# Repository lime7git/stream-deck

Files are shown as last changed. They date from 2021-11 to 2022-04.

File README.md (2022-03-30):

# stream-deck
 
TO DO:

- ADD RESET BUTTON                                     #CHECK
- CHANGE SWD TO GOLDPINS                               #CHECK
- ADD TWO STATUS LED DIODES                            #CHECK
- ADD FOOTPRINTS FOR MX CHERRY REPLACEMENT SWITCHES    #CHECK
- ADD TEST POINTS                                      #CHECK

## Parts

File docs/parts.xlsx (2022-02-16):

Name | Description | Qty | Price | Link
STMicroelectronics STM32F401RCT6 | Microcontroller | 1.0 | 6.723 USD | STM32F401RCT - lcsc.com (https://lcsc.com/product-detail/ST-Microelectronics_STMicroelectronics-STM32F401RCT6_C74524.html)
CHERRY MX 540-MX1A-E1NW | Mechanical pushbutton switch | 9.0 | 0.958 USD | cherry mx - mouser.com (https://pl.mouser.com/ProductDetail/CHERRY/MX1A-E1NW?qs=Z7NFYKyvgJd45Wm4xzFv7w%3D%3D)
ENKODER | Mechanical incremental encoder with switch EC11 | 3.0 | 4.360 USD | enkoder botland (https://botland.com.pl/enkodery/6903-enkoder-z-przyciskiem-20-impulsow-12mm-ec11-pionowy-5szt.html)
LED RGB WS2812B RING | Ring of 8 RGB LED diodes | 1.0 | 2.500 USD | ws2812 RGB LED - botland.pl (https://botland.com.pl/lancuchy-i-matryce-led/6248-pierscien-led-rgb-ws2812b-5050-x-8-diod-30mm.html)
OR Gate | 3 input OR gate for microcontroller reset procedure | 1.0 | 0.126 USD | OR gate - lcsc.com (https://www.lcsc.com/product-detail/Gates_onsemi-NC7SZ332P6X_C185032.html)
WS2812B | Adressable RGB LED diode | 6.0 | 0.058 USD | WS2812B - lcsc.com (https://lcsc.com/product-detail/Light-Emitting-Diodes-LED_XINGLIGHT-XL-5050RGBC-WS2812B_C2843785.html)
 |  |  | SUM
 |  |  | 31.40 USD

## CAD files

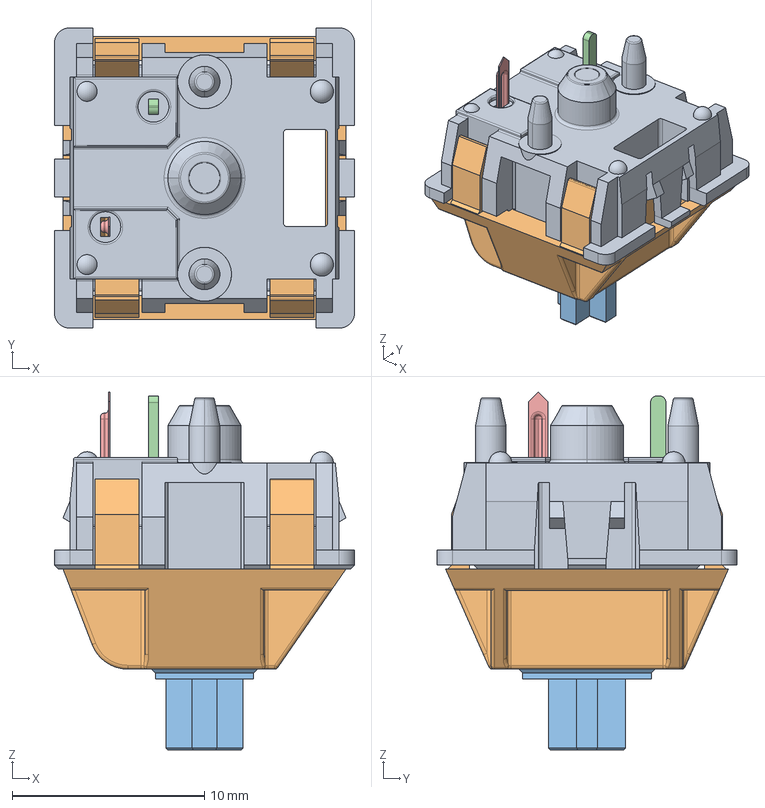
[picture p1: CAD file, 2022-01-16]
pcb/cherry-mx-3d-model/asm_mx_asm_PCB.stp
15.6 x 15.6 x 18.6 mm
MX_DOWN
MX_UP
UP_MX
MX_PIN
MX_SPRING
MX_CLICK

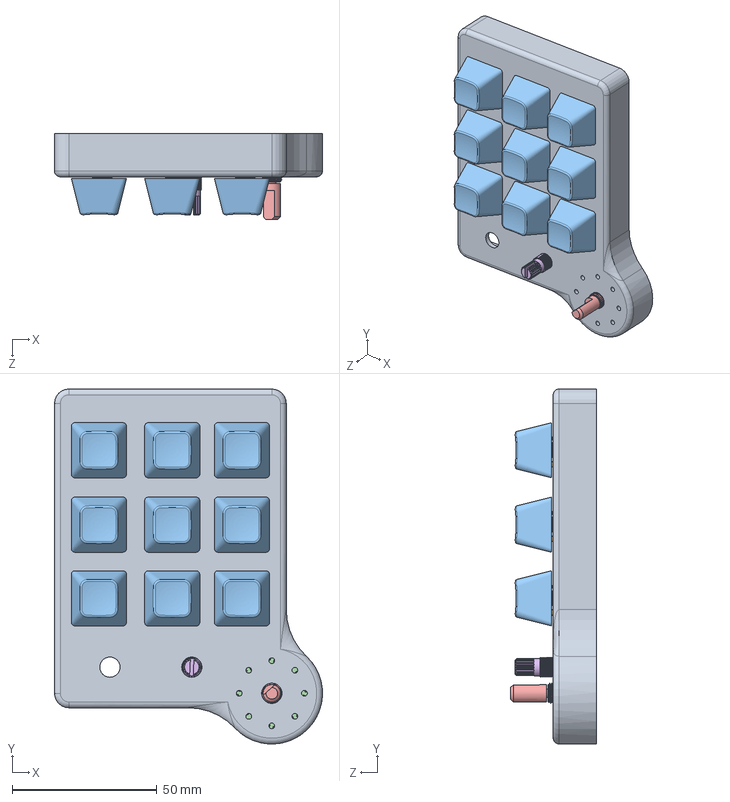
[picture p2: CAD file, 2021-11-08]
3d-model/Złożenie1.SLDASM
92.5 x 122.5 x 29.8 mm
case
cherry_mx x 9
keycap_dsa_signatureplastics_r3 x 9
WS2812_RING_8X
mechanical-encoder
Standard Potentiometer - Horizontal

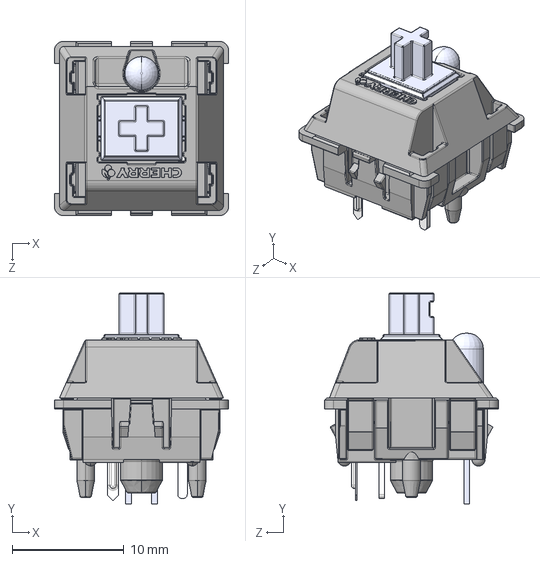
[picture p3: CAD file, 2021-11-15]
3d-model/cherry_mx.STEP
15.6 x 18.9 x 15.6 mm

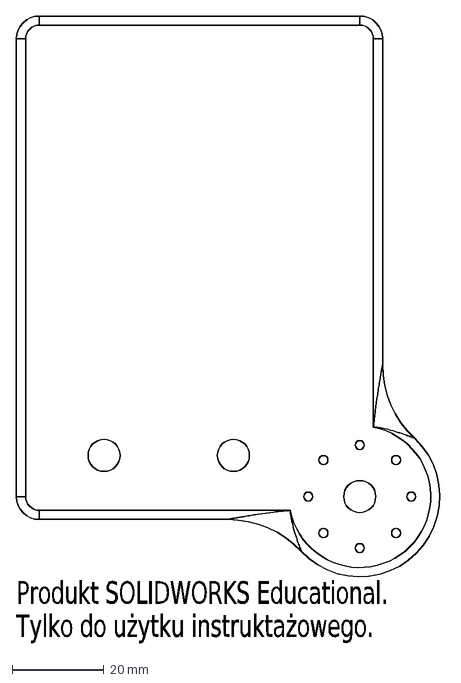
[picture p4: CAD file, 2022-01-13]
pcb/board-edges.DXF
Produkt SOLIDWORKS Educational.
Tylko do użytku instruktażowego.

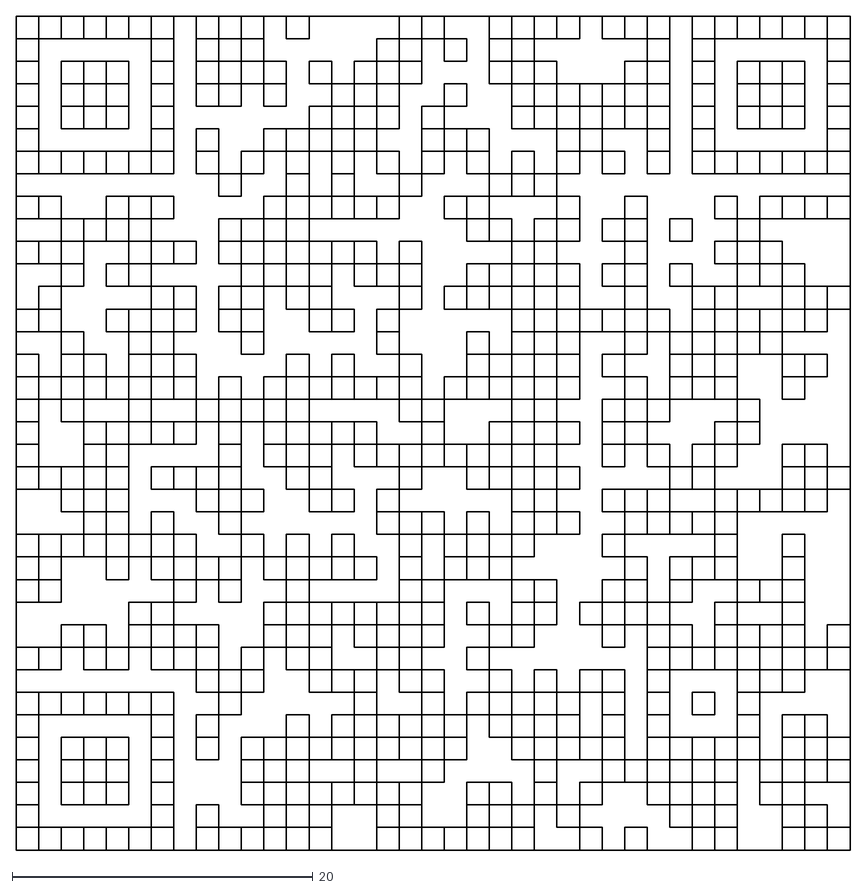
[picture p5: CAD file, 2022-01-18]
pcb/qr-code/qr-code.dxf
55.5 x 55.5

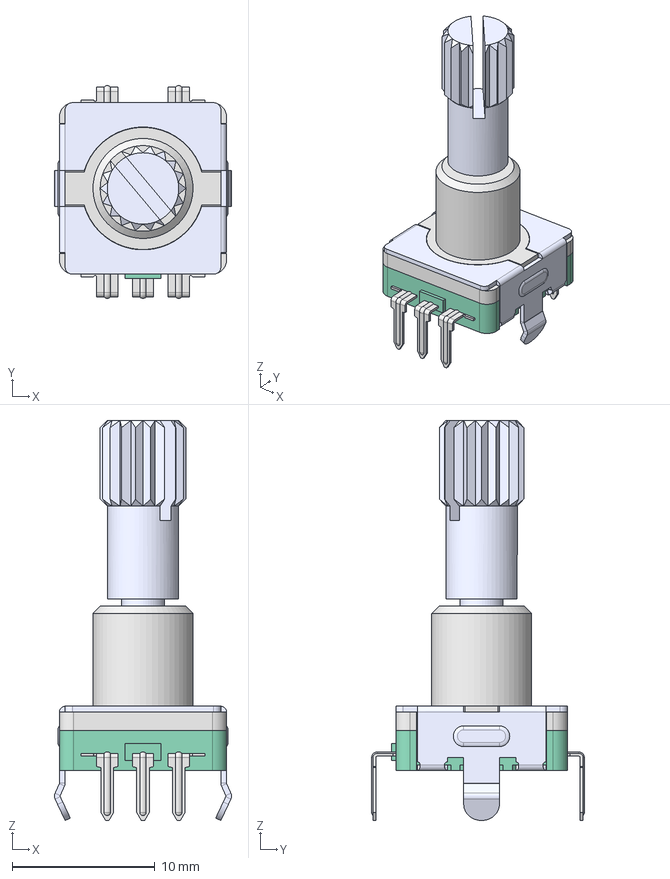
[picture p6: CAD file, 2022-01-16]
pcb/rotary-encoder-3d-model/EC11-THT-20K-green.step
12.4 x 14.9 x 28.0 mm
Lb7
20K
EC11-Housing-THT

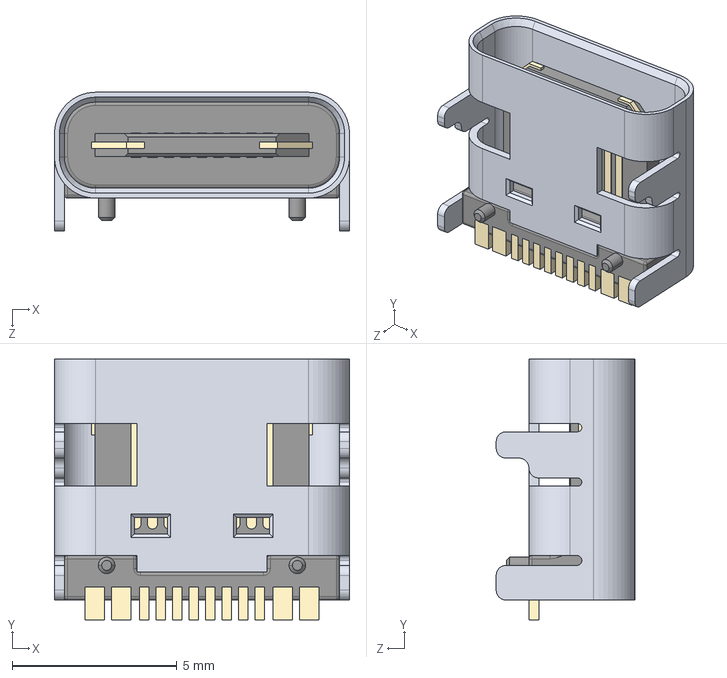
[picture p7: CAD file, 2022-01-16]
pcb/usb-c-smd-3d-model/USB Type C Port (SMD Type).STEP
8.94 x 7.90 x 4.20 mm

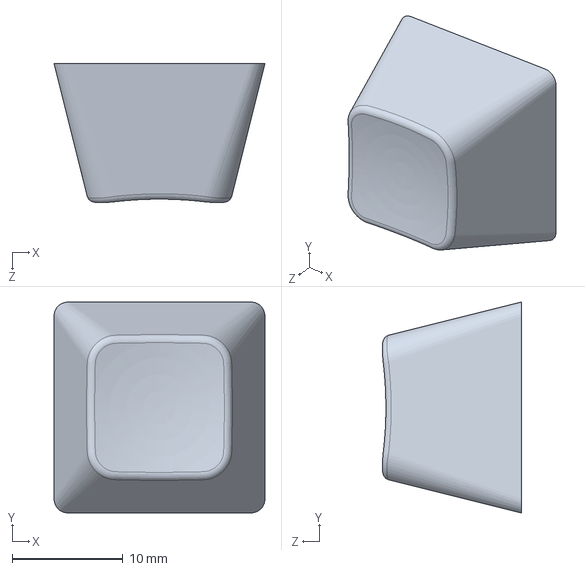
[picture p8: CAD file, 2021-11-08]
3d-model/keycap_dsa_signatureplastics_r3.SLDPRT
19.1 x 19.1 x 12.6 mm

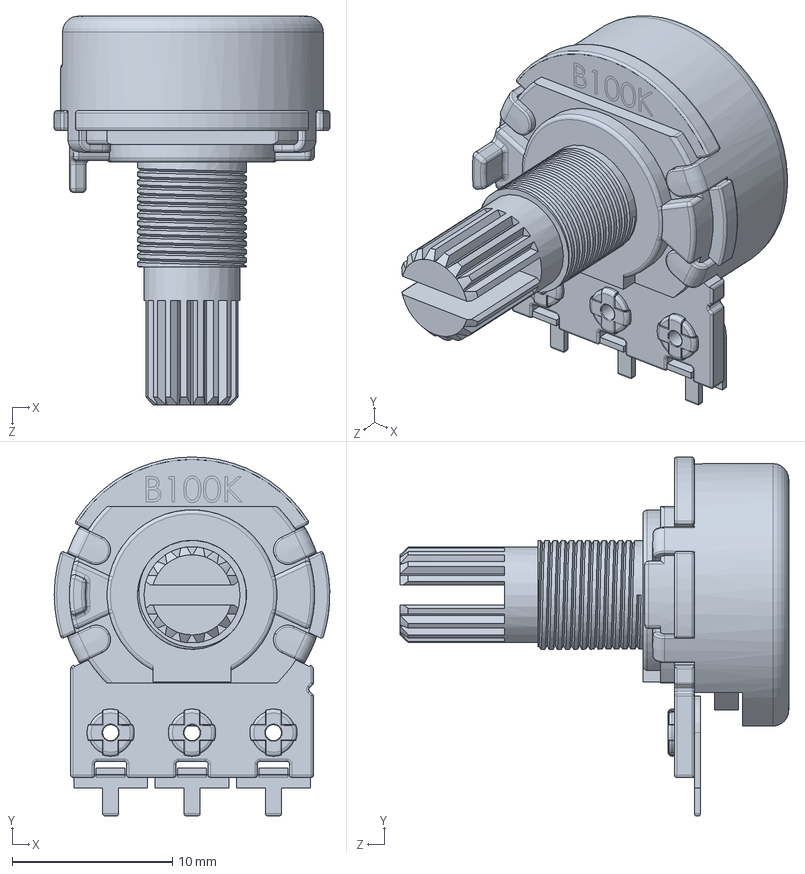
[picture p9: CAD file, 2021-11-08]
3d-model/Standard Potentiometer - Horizontal.SLDPRT
17.2 x 22.4 x 24.2 mm

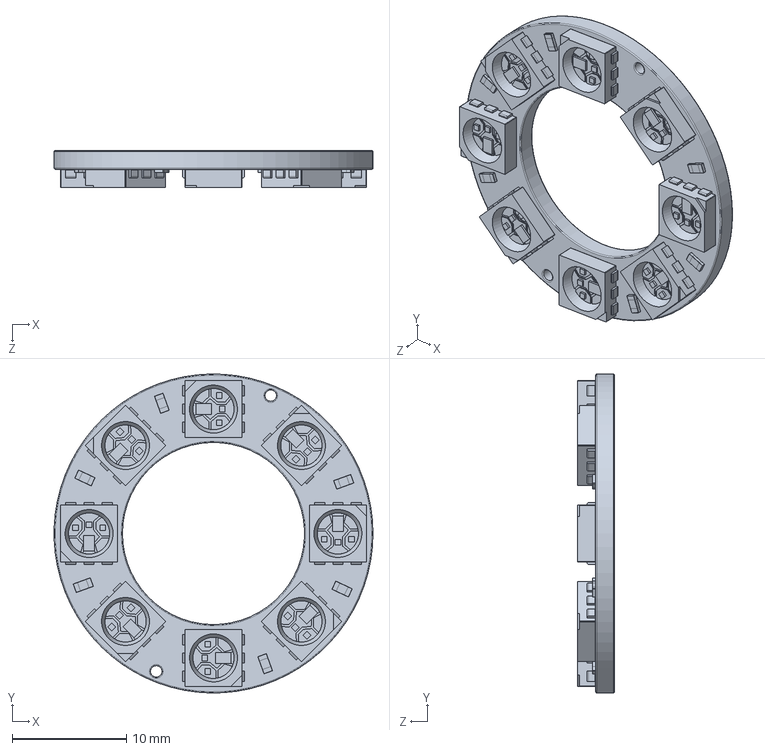
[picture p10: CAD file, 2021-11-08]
3d-model/WS2812_RING_8X.SLDPRT
28.0 x 27.9 x 3.25 mm

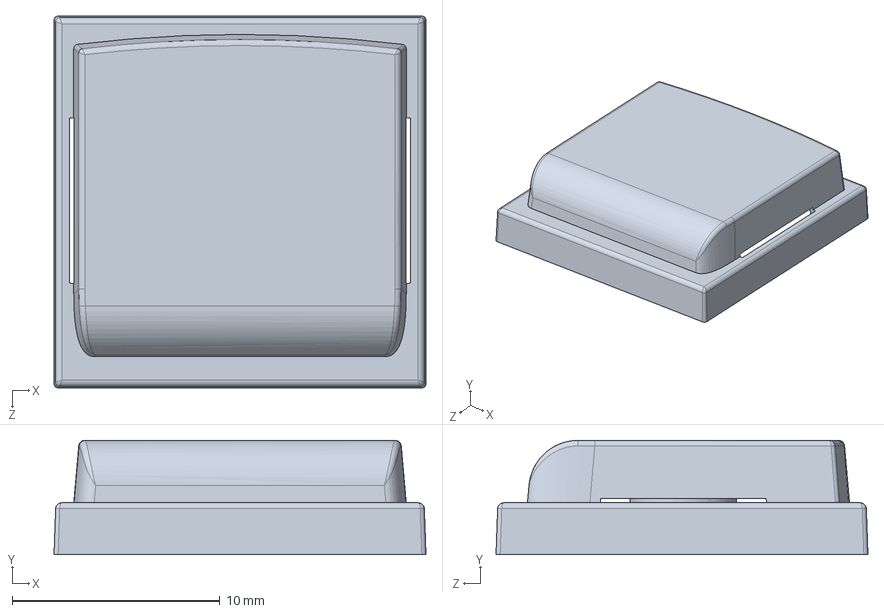
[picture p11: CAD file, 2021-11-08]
3d-model/KEY CAP-CHERRY-MX.SLDPRT
17.9 x 5.50 x 17.9 mm

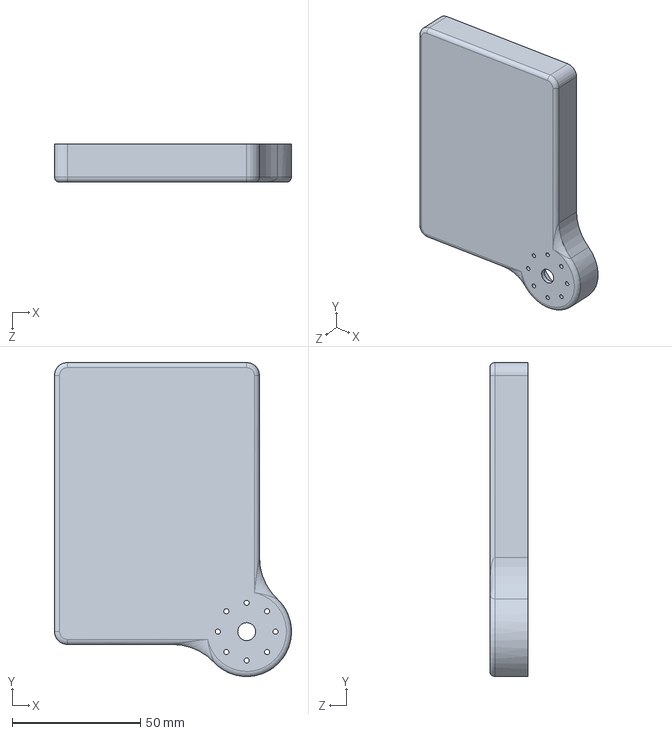
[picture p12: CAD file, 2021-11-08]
3d-model/case.SLDPRT
92.5 x 122.5 x 15.0 mm

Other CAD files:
3d-model/mechanical-encoder.SLDPRT
3d-model/cherry_mx.SLDPRT

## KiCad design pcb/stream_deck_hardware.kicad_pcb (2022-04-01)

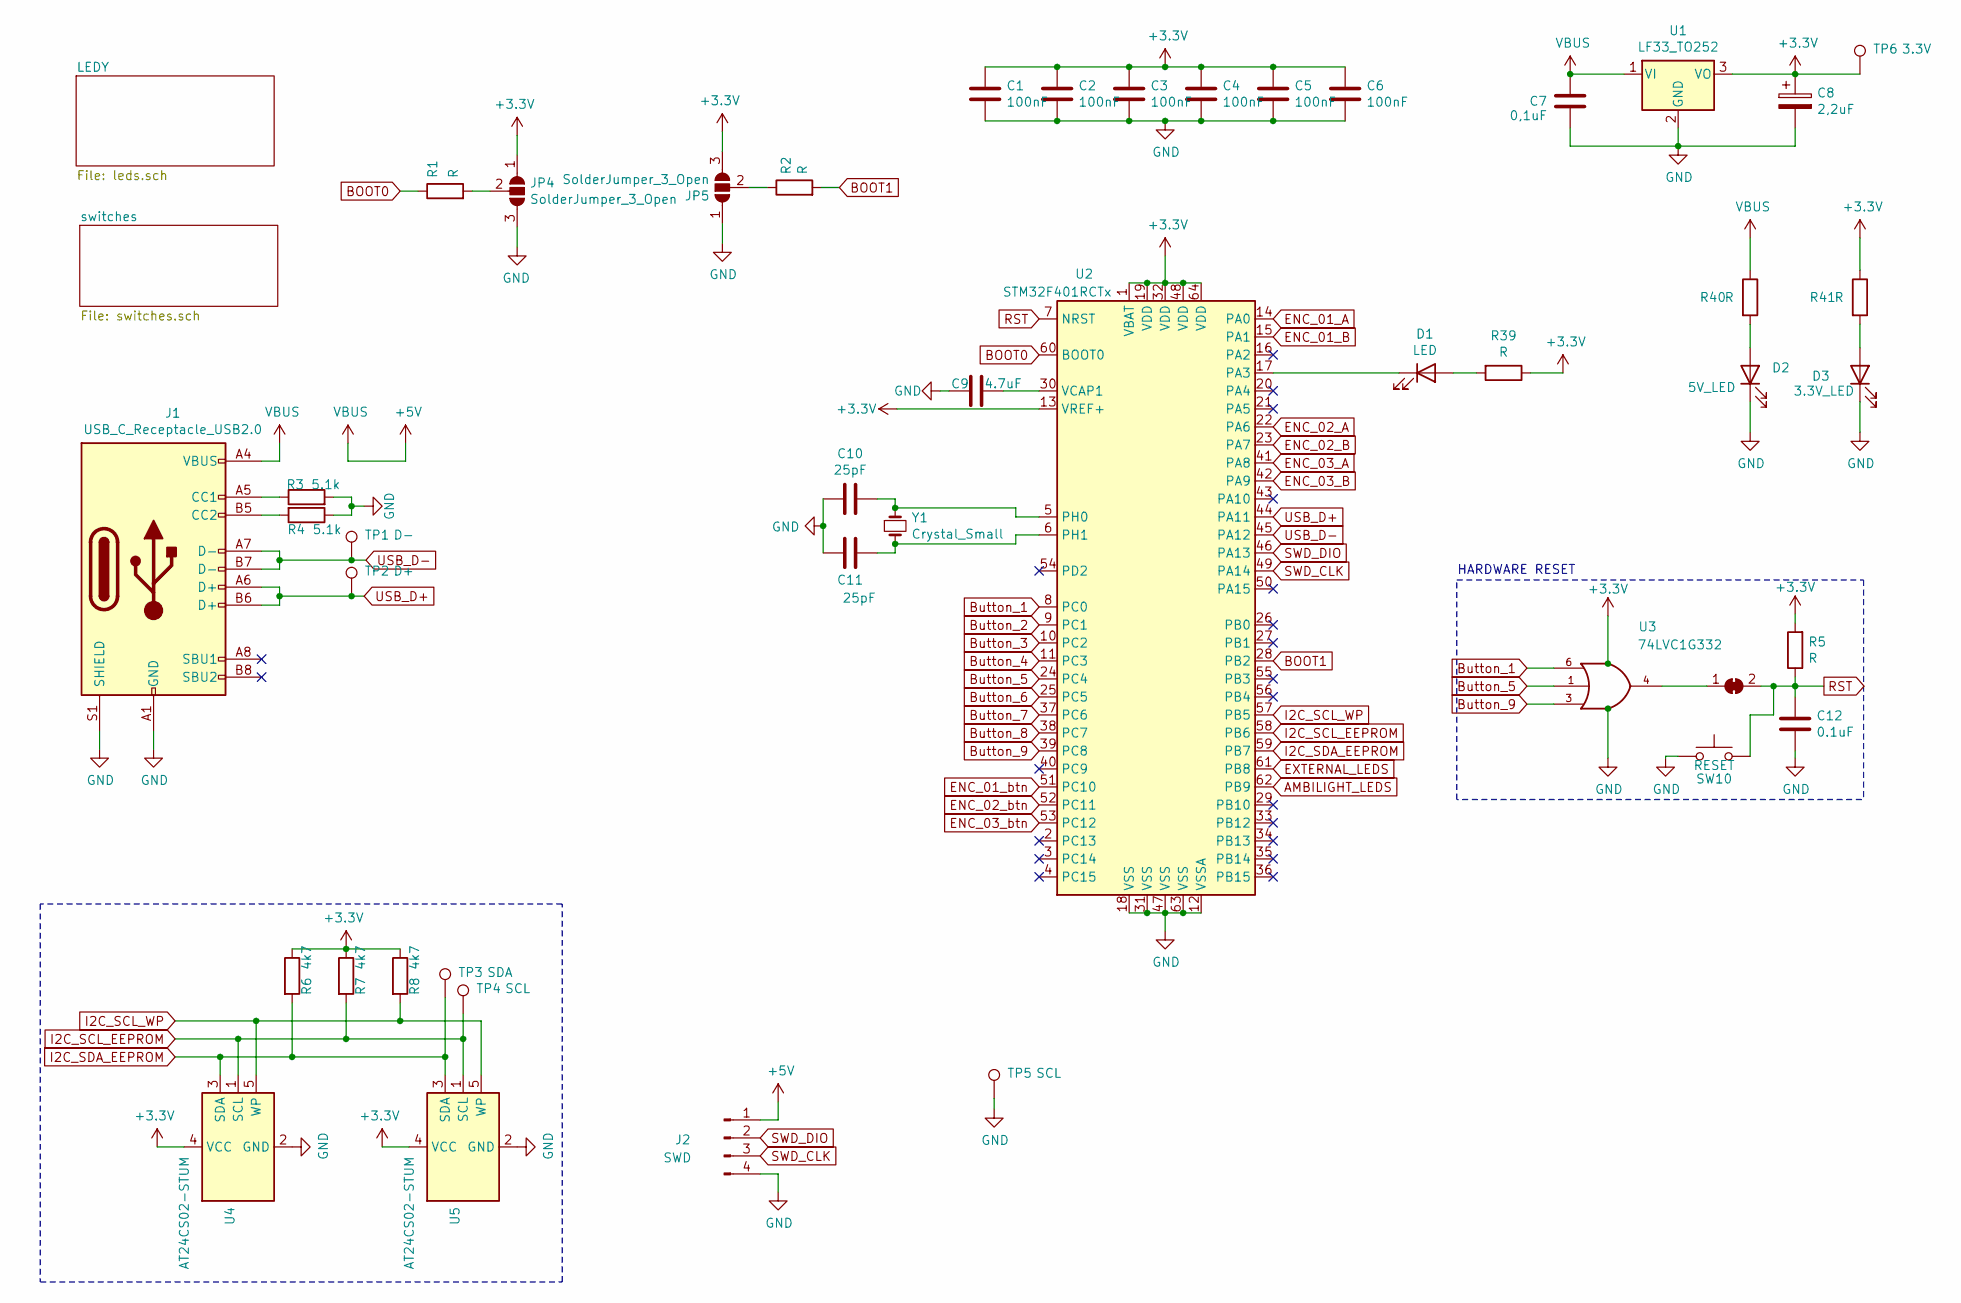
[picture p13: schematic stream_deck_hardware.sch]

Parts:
C1, C2, C3, C4, C5, C6: 100nF; C_0603_1608Metric
C7: 0,1uF; C_0603_1608Metric
C8: 2,2uF; C_0603_1608Metric
C9: 4.7uF; C_0603_1608Metric
C10, C11: 25pF; C_0603_1608Metric
C12: 0.1uF; C_0603_1608Metric
D1: LED; LED_0805_2012Metric
D2: 5V_LED; LED_0805_2012Metric
D3: 3.3V_LED; LED_0805_2012Metric
J1: USB_C_Receptacle_USB2.0; USB_C_Receptacle_Palconn_UTC16-G
J2: SWD; PinHeader_1x04_P2.54mm_Vertical
JP3: SolderJumper_2_Bridged; SolderJumper-2_P1.3mm_Bridged2Bar_RoundedPad1.0x1.5mm
JP4, JP5: SolderJumper_3_Open; SolderJumper-3_P1.3mm_Open_RoundedPad1.0x1.5mm
R1, R2, R5, R39, R40, R41: R; R_0603_1608Metric
R3, R4: 5.1k; R_0603_1608Metric
R6, R7, R8: 4k7; R_0603_1608Metric
SW10: RESET; SW_PUSH_6mm
TP1: D-; TestPoint_Pad_D2.0mm
TP2: D+; TestPoint_Pad_D2.0mm
TP3: SDA; TestPoint_Pad_D2.0mm
TP4, TP5: SCL; TestPoint_Pad_D2.0mm
TP6: 3.3V; TestPoint_Pad_D2.0mm
U1: LF33_TO252; TO-252-2
U2: STM32F401RCTx; LQFP-64_10x10mm_P0.5mm
U3: 74LVC1G332; SOT-23-6
U4, U5: AT24CS02-STUM; SOT-23-5
Y1: Crystal_Small; Crystal_HC49-U_Vertical

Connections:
+3V3: C1.1, C2.1, C3.1, C4.1, C5.1, C6.1, C8.1, JP4.1 (A), JP5.3 (B), R5.2, R6.1, R7.1, R8.1, R39.1, R41.1, TP6.1, U1.3 (VO), U2.1 (VBAT), U2.13 (VREF+), U2.19 (VDD), U2.32 (VDD), U2.48 (VDD), U2.64 (VDD), U3.5 (VCC), U4.4 (VCC), U5.4 (VCC); also elsewhere on the board
+5V: C7.1, J1.A4 (VBUS), J1.A9 (VBUS), J1.B4 (VBUS), J1.B9 (VBUS), J2.1, R40.1, U1.1 (VI); also elsewhere on the board
AMBILIGHT_LEDS: U2.62 (PB9); also elsewhere on the board
BOOT0: R1.1, U2.60 (BOOT0)
BOOT1: R2.2, U2.28 (PB2)
Button_1: U2.8 (PC0), U3.6; also elsewhere on the board
Button_2: U2.9 (PC1); also elsewhere on the board
Button_3: U2.10 (PC2); also elsewhere on the board
Button_4: U2.11 (PC3); also elsewhere on the board
Button_5: U2.24 (PC4), U3.1; also elsewhere on the board
Button_6: U2.25 (PC5); also elsewhere on the board
Button_7: U2.37 (PC6); also elsewhere on the board
Button_8: U2.38 (PC7); also elsewhere on the board
Button_9: U2.39 (PC8), U3.3; also elsewhere on the board
ENC_01_A: U2.14 (PA0); also elsewhere on the board
ENC_01_B: U2.15 (PA1); also elsewhere on the board
ENC_01_btn: U2.51 (PC10); also elsewhere on the board
ENC_02_A: U2.22 (PA6); also elsewhere on the board
ENC_02_B: U2.23 (PA7); also elsewhere on the board
ENC_02_btn: U2.52 (PC11); also elsewhere on the board
ENC_03_A: U2.41 (PA8); also elsewhere on the board
ENC_03_B: U2.42 (PA9); also elsewhere on the board
ENC_03_btn: U2.53 (PC12); also elsewhere on the board
EXTERNAL_LEDS: U2.61 (PB8); also elsewhere on the board
GND: C1.2, C2.2, C3.2, C4.2, C5.2, C6.2, C7.2, C8.2, C9.1, C10.2, C11.2, C12.2, D2.1 (K), D3.1 (K), J1.A1 (GND), J1.A12 (GND), J1.B1 (GND), J1.B12 (GND), J1.S1 (SHIELD), J2.4, JP4.3 (B), JP5.1 (A), R3.2, R4.1, SW10.1, TP5.1, U1.2 (GND), U2.12 (VSSA), U2.18 (VSS), U2.31 (VSS), U2.47 (VSS), U2.63 (VSS), U3.2 (GND), U4.2 (GND), U5.2 (GND); also elsewhere on the board
I2C_SCL_EEPROM: R7.2, TP4.1, U2.58 (PB6), U4.1 (SCL), U5.1 (SCL)
I2C_SCL_WP: R8.2, U2.57 (PB5), U4.5 (WP), U5.5 (WP)
I2C_SDA_EEPROM: R6.2, TP3.1, U2.59 (PB7), U4.3 (SDA), U5.3 (SDA)
unnamed: C9.2, U2.30 (VCAP1)
unnamed: C10.1, U2.5 (PH0), Y1.1
unnamed: C11.1, U2.6 (PH1), Y1.2
unnamed: D1.1 (K), U2.17 (PA3)
unnamed: D1.2 (A), R39.2
unnamed: D2.2 (A), R40.2
unnamed: D3.2 (A), R41.2
unnamed: J1.A5 (CC1), R3.1
unnamed: J1.B5 (CC2), R4.2
unnamed: JP3.1 (A), U3.4
unnamed: JP4.2 (C), R1.2
unnamed: JP5.2 (C), R2.1
RST: C12.1, JP3.2 (B), R5.1, SW10.2, U2.7 (NRST); also elsewhere on the board
SWD_CLK: J2.3, U2.49 (PA14); also elsewhere on the board
SWD_DIO: J2.2, U2.46 (PA13); also elsewhere on the board
USB_D+: J1.A6 (D+), J1.B6 (D+), TP2.1, U2.44 (PA11); also elsewhere on the board
USB_D-: J1.A7 (D-), J1.B7 (D-), TP1.1, U2.45 (PA12); also elsewhere on the board

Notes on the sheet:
HARDWARE RESET

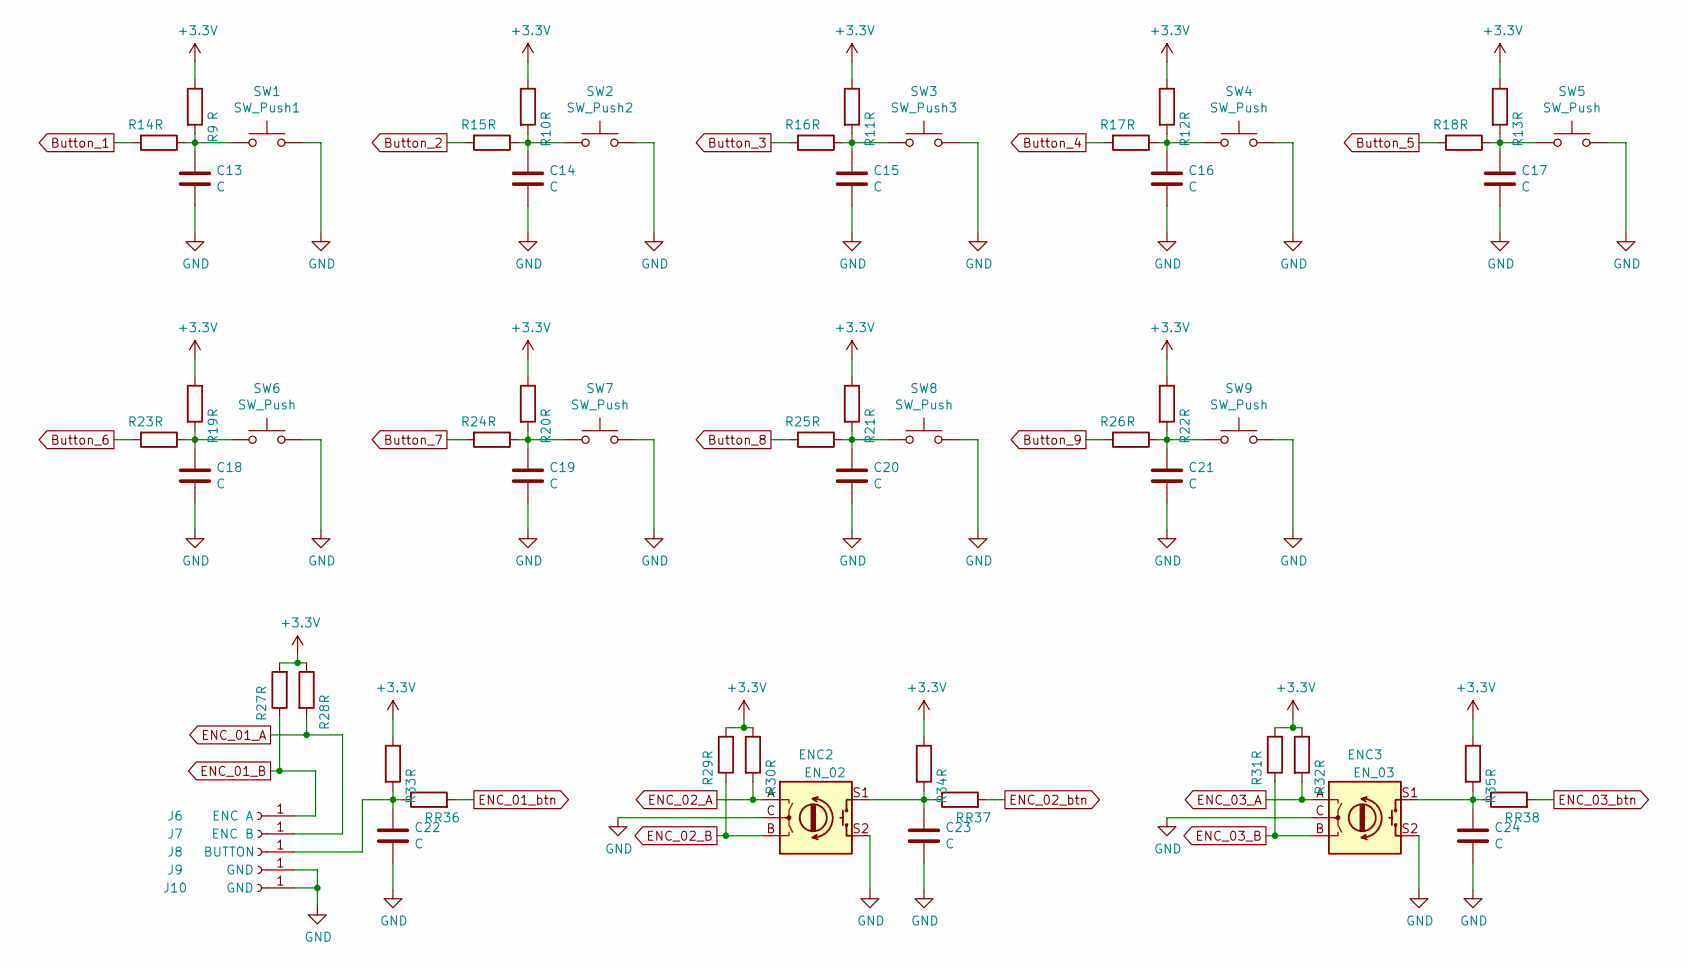
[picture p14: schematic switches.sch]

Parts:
C13, C14, C15, C16, C17, C18, C19, C20, C21, C22, C23, C24: C; C_0603_1608Metric
ENC2: EN_02; RotaryEncoder_Alps_EC11E-Switch_Vertical_H20mm_CircularMoun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
ENC3: EN_03; RotaryEncoder_Alps_EC11E-Switch_Vertical_H20mm_CircularMoun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
J6: ENC A; TestPoint_Pad_D2.0mm
J7: ENC B; TestPoint_Pad_D2.0mm
J8: BUTTON; TestPoint_Pad_D2.0mm
J9, J10: GND; TestPoint_Pad_D2.0mm
R9, R10, R11, R12, R13, R14, R15, R16, R17, R18, R19, R20, R21, R22, R23, R24, R25, R26, R27, R28, R29, R30, R31, R32, R33, R34, R35, R36, R37, R38: R; R_0603_1608Metric
SW1: SW_Push1; SW_Cherry_MX_1.00u_PCB
SW2: SW_Push2; SW_Cherry_MX_1.00u_PCB
SW3: SW_Push3; SW_Cherry_MX_1.00u_PCB
SW4, SW5, SW6, SW7, SW8, SW9: SW_Push; SW_Cherry_MX_1.00u_PCB

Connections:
+3V3: R9.1, R10.1, R11.1, R12.1, R13.1, R19.1, R20.1, R21.1, R22.1, R27.2, R28.1, R29.2, R30.1, R31.2, R32.1, R33.1, R34.1, R35.1; also elsewhere on the board
Button_1: R14.2; also elsewhere on the board
Button_2: R15.2; also elsewhere on the board
Button_3: R16.2; also elsewhere on the board
Button_4: R17.2; also elsewhere on the board
Button_5: R18.2; also elsewhere on the board
Button_6: R23.2; also elsewhere on the board
Button_7: R24.2; also elsewhere on the board
Button_8: R25.2; also elsewhere on the board
Button_9: R26.2; also elsewhere on the board
ENC_01_A: J7.1, R28.2; also elsewhere on the board
ENC_01_B: J6.1, R27.1; also elsewhere on the board
ENC_01_btn: R36.2; also elsewhere on the board
ENC_02_A: ENC2.A, R30.2; also elsewhere on the board
ENC_02_B: ENC2.B, R29.1; also elsewhere on the board
ENC_02_btn: R37.2; also elsewhere on the board
ENC_03_A: ENC3.A, R32.2; also elsewhere on the board
ENC_03_B: ENC3.B, R31.1; also elsewhere on the board
ENC_03_btn: R38.2; also elsewhere on the board
GND: C13.2, C14.2, C15.2, C16.2, C17.2, C18.2, C19.2, C20.2, C21.2, C22.2, C23.2, C24.2, ENC2.C, ENC2.S2, ENC3.C, ENC3.S2, J9.1, J10.1, SW1.2, SW2.2, SW3.2, SW4.2, SW5.2, SW6.2, SW7.2, SW8.2, SW9.2; also elsewhere on the board
unnamed: C13.1, R9.2, R14.1, SW1.1
unnamed: C14.1, R10.2, R15.1, SW2.1
unnamed: C15.1, R11.2, R16.1, SW3.1
unnamed: C16.1, R12.2, R17.1, SW4.1
unnamed: C17.1, R13.2, R18.1, SW5.1
unnamed: C18.1, R19.2, R23.1, SW6.1
unnamed: C19.1, R20.2, R24.1, SW7.1
unnamed: C20.1, R21.2, R25.1, SW8.1
unnamed: C21.1, R22.2, R26.1, SW9.1
unnamed: C22.1, J8.1, R33.2, R36.1
unnamed: C23.1, ENC2.S1, R34.2, R37.1
unnamed: C24.1, ENC3.S1, R35.2, R38.1

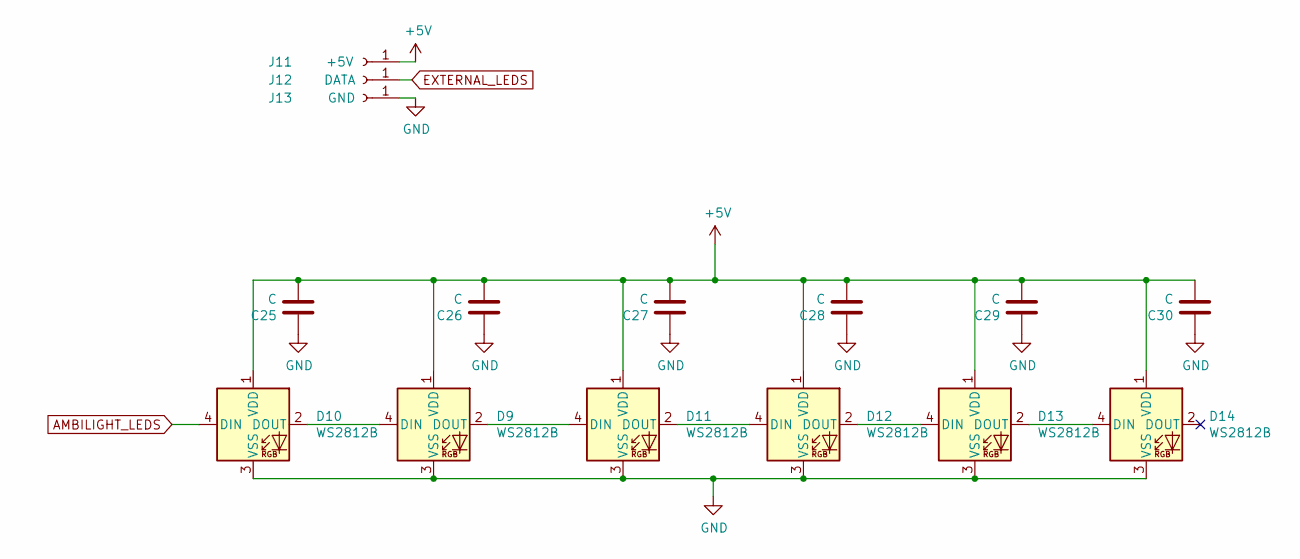
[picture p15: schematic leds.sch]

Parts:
C25, C26, C27, C28, C29, C30: C; C_0603_1608Metric
D9, D10, D11, D12, D13, D14: WS2812B; LED_WS2812B_PLCC4_5.0x5.0mm_P3.2mm
J11: +5V; TestPoint_Pad_D2.0mm
J12: DATA; TestPoint_Pad_D2.0mm
J13: GND; TestPoint_Pad_D2.0mm

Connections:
+5V: C25.2, C26.2, C27.2, C28.2, C29.2, C30.2, D9.1 (VDD), D10.1 (VDD), D11.1 (VDD), D12.1 (VDD), D13.1 (VDD), D14.1 (VDD), J11.1; also elsewhere on the board
AMBILIGHT_LEDS: D10.4 (DIN); also elsewhere on the board
EXTERNAL_LEDS: J12.1; also elsewhere on the board
GND: C25.1, C26.1, C27.1, C28.1, C29.1, C30.1, D9.3 (VSS), D10.3 (VSS), D11.3 (VSS), D12.3 (VSS), D13.3 (VSS), D14.3 (VSS), J13.1; also elsewhere on the board
unnamed: D9.4 (DIN), D10.2 (DOUT)
unnamed: D11.2 (DOUT), D12.4 (DIN)
unnamed: D9.2 (DOUT), D11.4 (DIN)
unnamed: D12.2 (DOUT), D13.4 (DIN)
unnamed: D13.2 (DOUT), D14.4 (DIN)

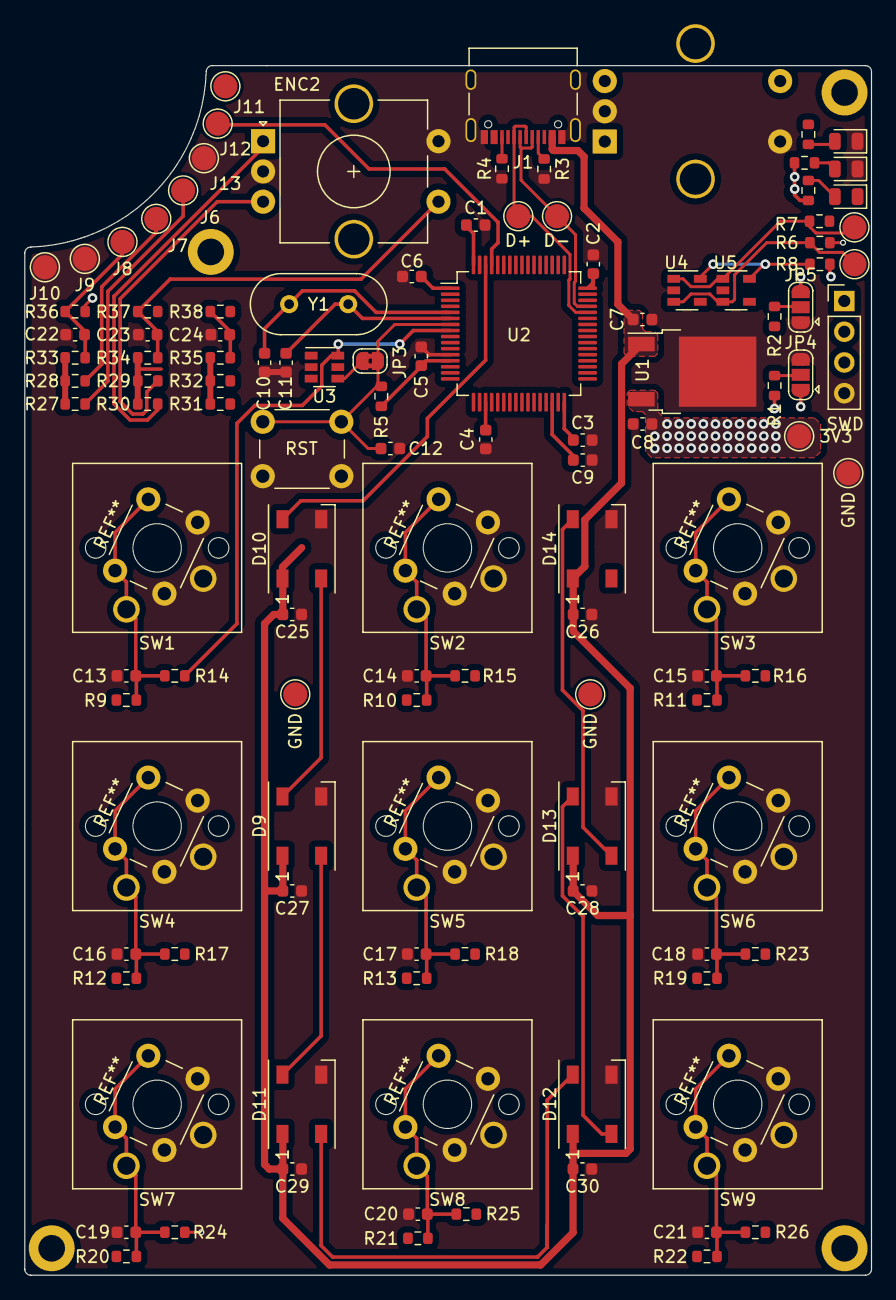
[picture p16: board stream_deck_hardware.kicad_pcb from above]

Board: 4 copper layers, 70.0 x 100.0 mm, 119 parts (1 on the bottom side), 62 nets.

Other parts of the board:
3V3: 3.3V; TestPoint_Pad_D2.0mm
D+: D+; TestPoint_Pad_D2.0mm
D-: D-; TestPoint_Pad_D2.0mm
GND: SCL; TestPoint_Pad_D2.0mm
GND#2, GND#3: SCL; TestPoint_Pad_D2.0mm
RST: RESET; SW_PUSH_6mm
SWD: SWD; PinHeader_1x04_P2.54mm_Vertical

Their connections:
+3V3: 3V3.1; also elsewhere on the board
+5V: SWD.1; also elsewhere on the board
GND: GND#3.1, RST.1, SWD.4; also elsewhere on the board
RST: RST.2; also elsewhere on the board
SWD_CLK: SWD.3; also elsewhere on the board
SWD_DIO: SWD.2; also elsewhere on the board
USB_D+: D+.1; also elsewhere on the board
USB_D-: D-.1; also elsewhere on the board

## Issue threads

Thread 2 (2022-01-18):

Change footprints

lime7git, 2022-01-18:
Could You please change J4, J5 and J6 footprints from goldpin connectors to solder wire pads.

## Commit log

2021-11-08 Added excel sheet with needed parts
    [parts.xlsx]
2021-11-08 case
    First sugestion of stream-deck case
    [case.SLDPRT]
2021-11-08 Added encoder cad model and excel sheet with needed parts
    [EC11-THT-20R-thread-black.step, parts.xlsx]
2021-11-08 Change encoder
    [EC11-THT-20F-thread-black.step, EC11-THT-20R-thread-black.step]
2021-11-08 First concept of electronic case
    assembly in SOLIDWORKS
    [KEY CAP-CHERRY-MX.SLDPRT, Standard Potentiometer - Horizontal.SLDPRT, WS2812_RING_8X.SLDPRT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]
2021-11-08 Excel update
    [parts.xlsx]
2021-11-15 Kicad designing PCB
    Kicad
    [cherry_mx.STEP, stream_deck_hardware.kicad_pcb, stream_deck_hardware.sch]
2021-11-15 electrical schematic desiging
    [cherry_mx.SLDPRT, leds.sch, stream_deck_hardware.sch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]
2021-11-15 Added some datesheets
    [parts.xlsx]
2021-11-15 Clean up
    [leds.sch, stream_deck_hardware.kicad_pcb, stream_deck_hardware.sch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]
2021-11-17 Schematic upgrade
    [stream_deck_hardware.sch]
2021-11-17 Added boot pins jumper selector
    [stream_deck_hardware.sch]
2021-11-17 Added STM32 boot modes application note AN2606
2021-11-18 Schematic update
    [stream_deck_hardware.sch]
2021-11-18 Schematic version 1.0
    [leds.sch, stream_deck_hardware.sch, switches.sch]
2021-11-18 Added EEPROM memory & some footprints
    [leds.sch, stream_deck_hardware.sch, switches.sch]
2022-01-13 Finish schematic and added footprints
    [leds.sch, stream_deck_hardware.sch, switches.sch]
2022-01-13 Footprints update and some changes
    [leds.sch, stream_deck_hardware.kicad_pcb, stream_deck_hardware.sch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]
2022-01-13 PCB edges prototype
    [board-edges.DXF, stream_deck_hardware.kicad_pcb]
2022-01-15 Components positioning
    [stream_deck_hardware.kicad_pcb, switches.sch]
2022-01-15 Components placement
    [stream_deck_hardware.kicad_pcb, stream_deck_hardware.sch]
2022-01-16 Components placement, added 3d model of cherry mx switch
    [asm_mx_asm_PCB.stp, stream_deck_hardware.kicad_pcb, switches.sch]
2022-01-16 Remove usb wire connector
    [stream_deck_hardware.kicad_pcb, stream_deck_hardware.sch]
2022-01-16 Added encoder, and usb-c 3d models
    [EC11-THT-20K-green.step, USB Type C Port (SMD Type).STEP, stream_deck_hardware.kicad_pcb]
2022-01-16 Component placement
    [stream_deck_hardware.kicad_pcb]
2022-01-18 Change connectors footprints
    [leds.sch, qr-code.dxf, stream_deck_hardware.kicad_pcb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]
2022-01-18 Pads placement
    [stream_deck_hardware.kicad_pcb, stream_deck_hardware.sch]
2022-01-19 Component placement version 1.0
    [stream_deck_hardware.kicad_pcb]
2022-03-30 puszuje to
    [stream_deck_hardware.kicad_pcb]
